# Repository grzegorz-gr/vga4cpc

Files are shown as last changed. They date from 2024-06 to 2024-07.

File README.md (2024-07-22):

# vga4cpc
VGA output for Amstrad CPC based on Raspberry Pi Pico.<br /> <br />

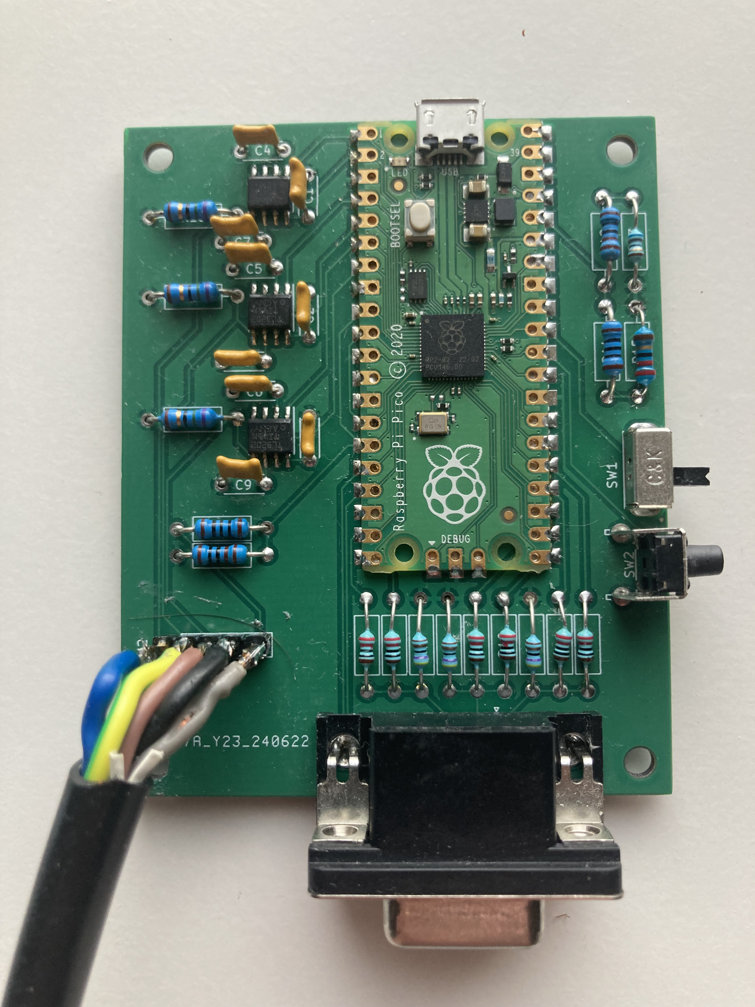
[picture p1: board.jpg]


The goal of this project was to build a scandoubler for Amstrad CPC that is cheap, simple to build and can handle the most popular tricks that Amstrad software does (e.g. smooth scroll) that standard scandoublers usually don't support.
It should work with most LCD monitors. It supports 50.08 FPS to make animations look smoother, but there is also an option to use 60 FPS, if your monitor does not support low frequencies.

Please keep in mind that I am a beginner in electronics, so I could make some serious mistakes. Use it on your own risk.

## Short demo
[https://youtu.be/5xjjsLVpjv0]

## How to build it
Gerber files are in "gerber" directory. I used them with JLCPCB. <br /><br />
Parts:<br />
|Symbol|Value|Quantity|Link|
|---|---|---|---|
|U1|Raspberry Pi Pico|1|[https://www.digikey.com/en/products/detail/raspberry-pi/SC0915/13624793]|
|U2-U4|TLV3202 voltage comparators|3|[https://www.digikey.com/en/products/detail/texas-instruments/TLV3202AIDR/3518740]|
|J1|VGA Socket|1|[https://www.digikey.com/en/products/detail/assmann-wsw-components/A-HDF15A-KG-TAXB/1241905] (Actually it did not fit perfectly, but it was possible to mount it)|
|C1-C9|0.1u ceramic capacitors|9|[https://www.digikey.com/en/products/detail/kyocera-avx/SR215C104JAR/2208907]|
|R1-R3|47 ohm resistors|3|[https://www.digikey.com/en/products/detail/stackpole-electronics-inc/RNMF14FTC47R0/2617352]|
|R4,R14|100 ohm resistors|2|[https://www.digikey.com/en/products/detail/yageo/MFR-25FRF52-100R/14795]|
|R5,R12|1 kOhm resistors|2|[https://www.digikey.com/en/products/detail/yageo/MFR-25FRF52-1K/14891]|
|R6-R11|220 Ohm resistors|6||[https://www.digikey.com/en/products/detail/stackpole-electronics-inc/RNMF14FTC220R/2617314]|
|R13|68 Ohm resistor|1|[https://www.digikey.com/en/products/detail/stackpole-electronics-inc/RNMF14FTC68R0/2617372]|
|R15|22 Ohm resistor|1|[https://www.digikey.com/en/products/detail/yageo/MFR-25FTE52-15R/9139795]|
|R16-R18|75 Ohm resistors|3|[https://www.digikey.com/en/products/detail/yageo/MFR-25FBF52-75R/12771]|
|SW1|50/60 FPS switch|1|[https://www.digikey.com/en/products/detail/c-k/OS102011MA1QS1/1981431]|
|SW2|Reset button|1|[https://www.digikey.com/en/products/detail/te-connectivity-alcoswitch-switches/1-1825027-1/1632544]|
|J2|CPC connection header|1|Just install whatever you need to connect to CPC. I used pin headers and soldered cables to them|
||Din 6 or Din 5 plug (center pin is not used) to connect it to Amstrad unless you plan to solder it directly to PCB|1||

<br /><br />
I wanted to make it easy to solder so almost all parts are TH. Raspberry Pi Pico and comparators are SMD (there was no TH option), but they are quite big and they are simple to solder even without a microscope.
<br /><br />
You need to connect it to Amstrad video port using J2 connector. The pins are: 1 - blue, 2 - green, 3 - red, 4 - GND, 5 - csync. You can connect din-6/din-5 plug there, or solder directly to Amstrad PCB.
<br /><br />
After (or before) building the PCB you just need to upload the software to RPI Pico. Connect it with USB cable to PC/Mac, keeping the small button on Pico board pressed. It should mount as a storage device. Just copy uf2 file there. Pico should unmount and restart then.

## How to use it
Connect 5V power adapter (or just cable to USB port in pc) to RPI Pico. Connect VGA cable to monitor. You can connect the board to Amstrad, but don't turn it on yet. You should see test screen with Amstrad palette on top, some potentially problematic patterns on bottom and 4 squares in corners. Make sure it looks OK. In case of any issues you can try to reset the board with SW2 button. It is also a good moment to try switching the V frequency with SW1 button. If 50.08hz works with your monitor, then use it. In other case, try 60Hz. If squares in corners are not fully visible (the image is shifted), try using Auto-adjust in your monitor.<br />
If everything looks OK, turn on your Amstrad and have fun.<br />

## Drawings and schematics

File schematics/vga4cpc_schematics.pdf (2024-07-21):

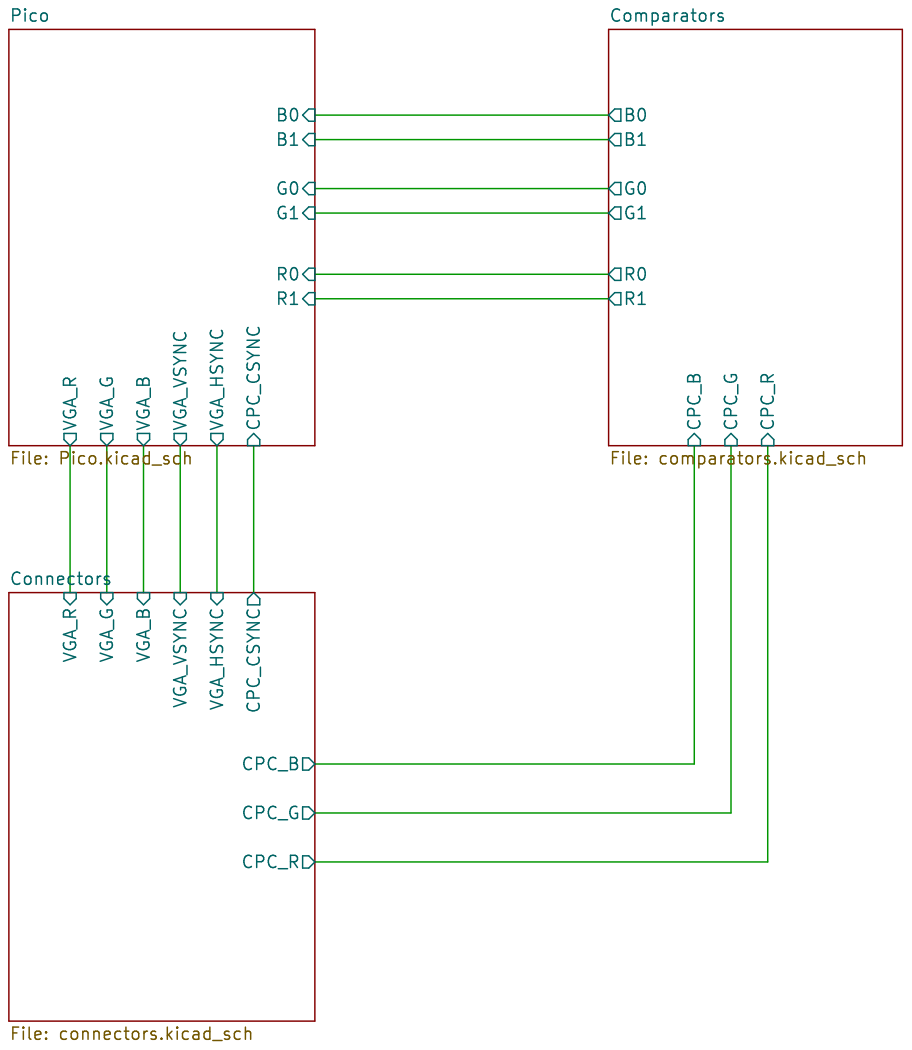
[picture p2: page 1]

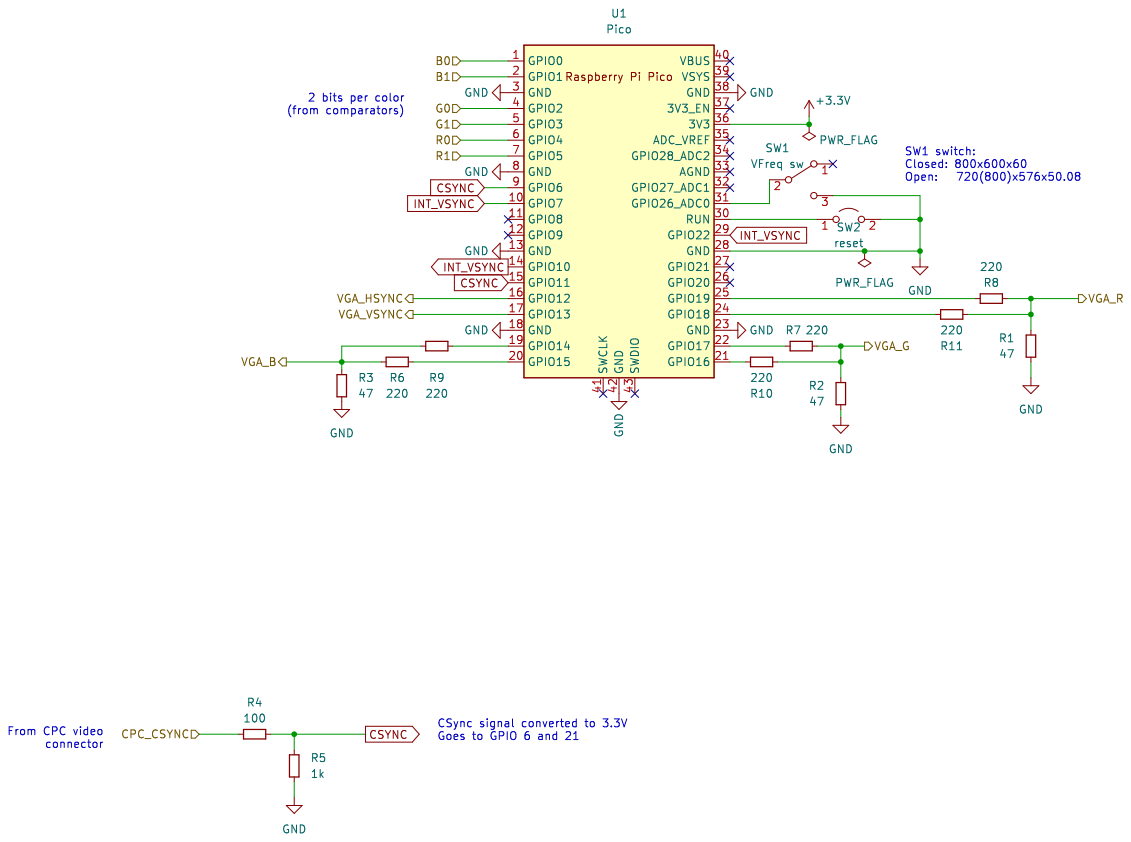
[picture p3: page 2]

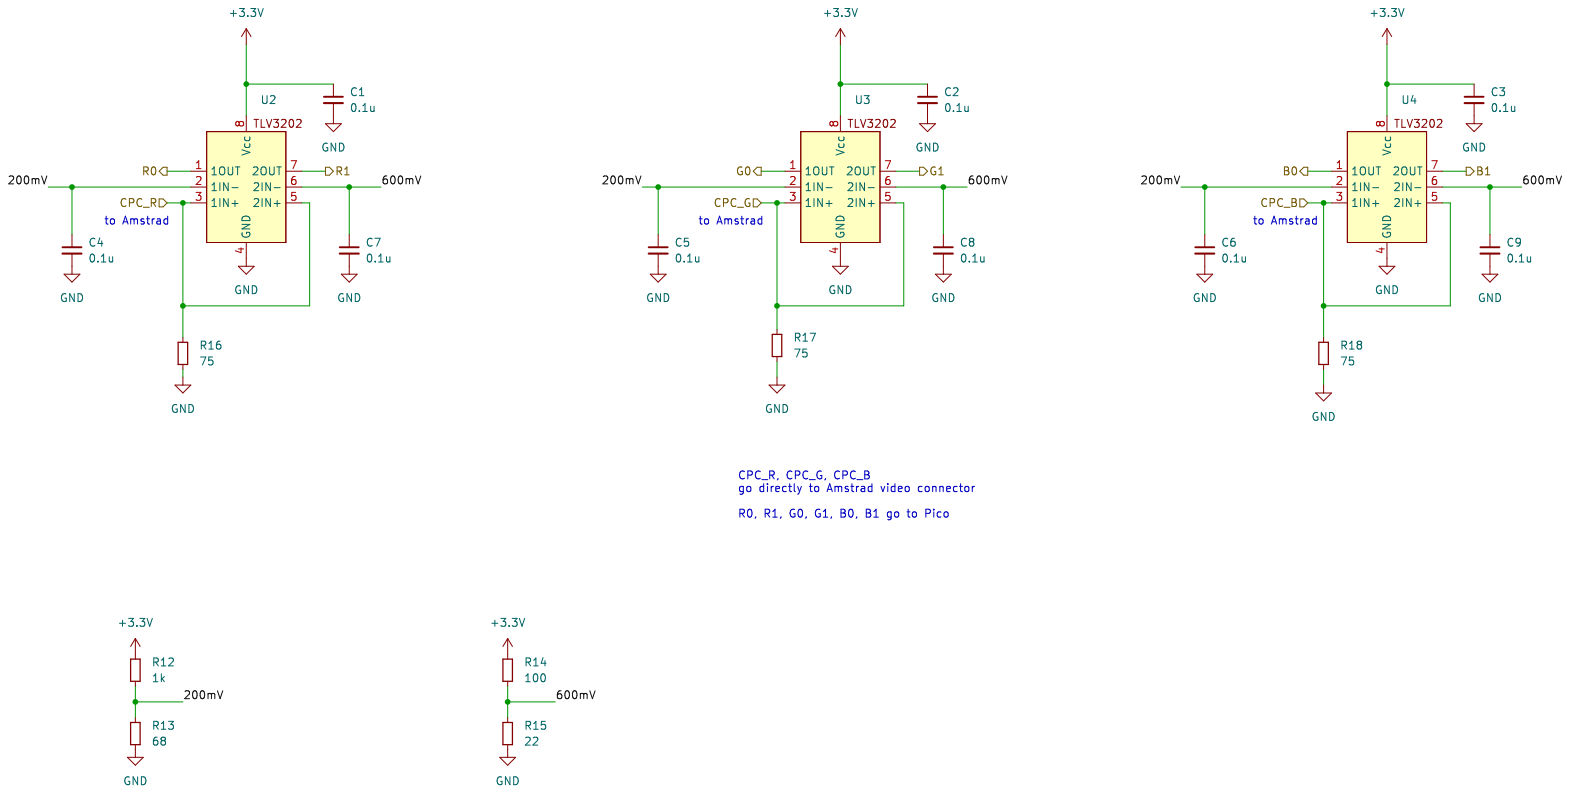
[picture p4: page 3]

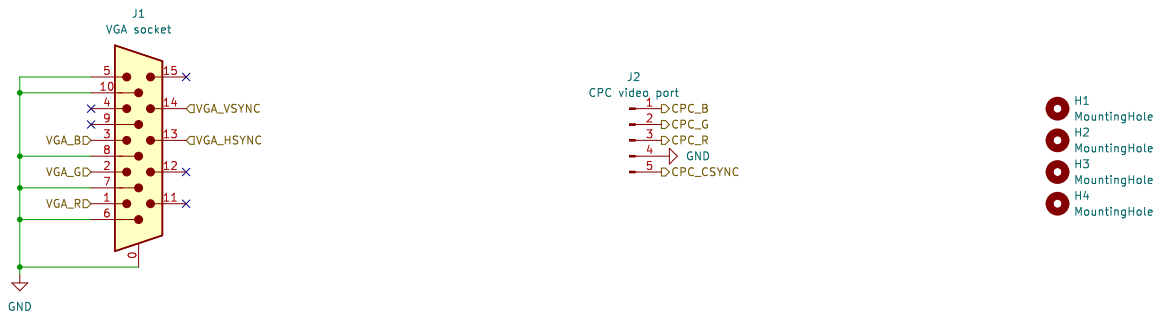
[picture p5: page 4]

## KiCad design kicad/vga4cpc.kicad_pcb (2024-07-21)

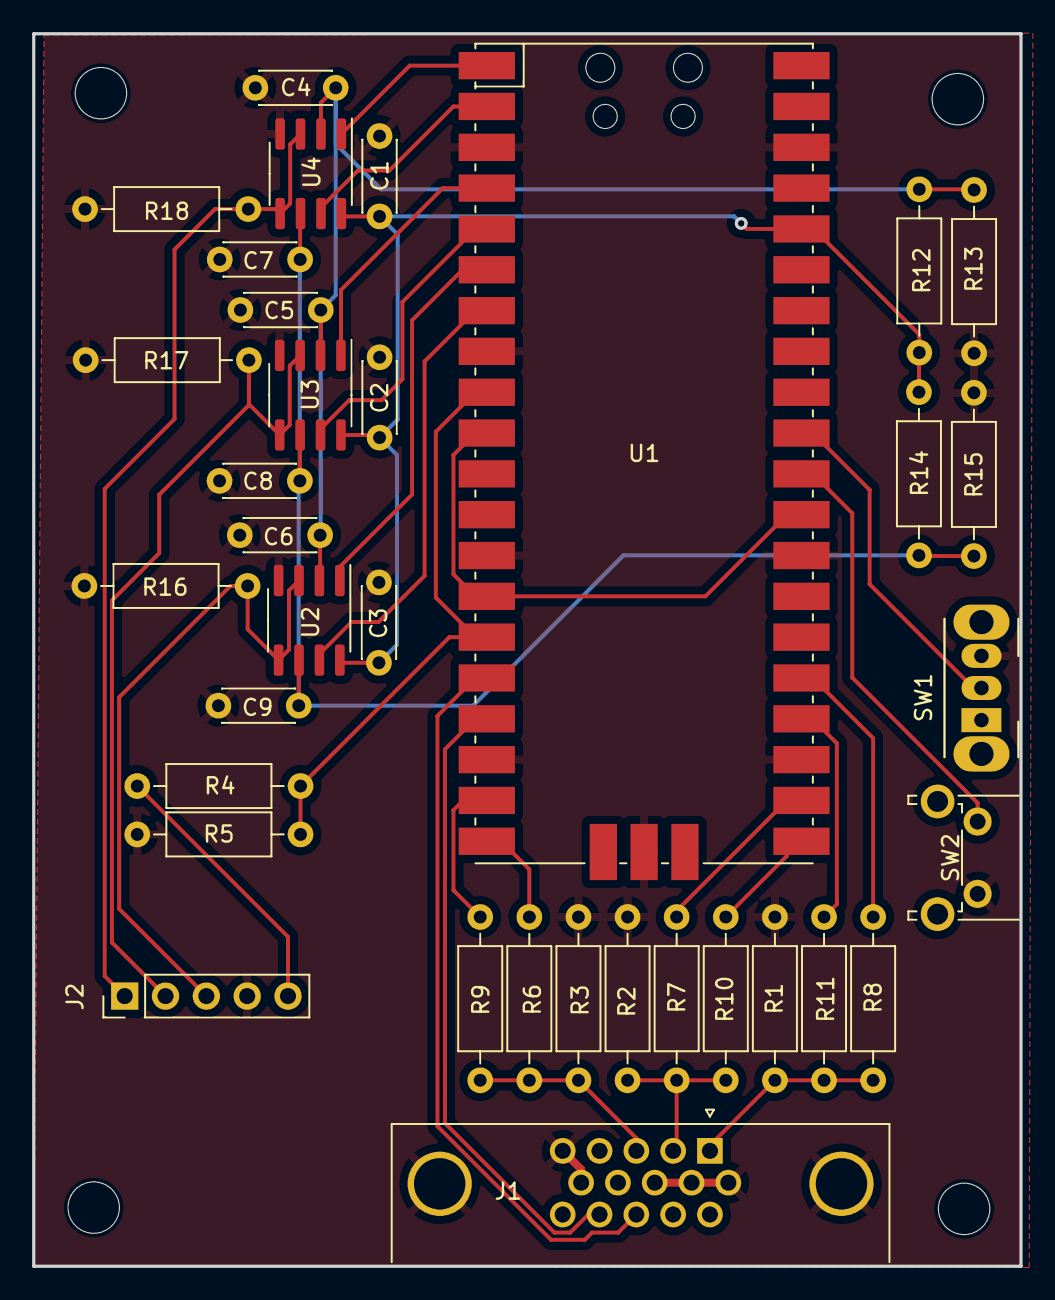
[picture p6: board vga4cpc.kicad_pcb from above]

Board: 2 copper layers, 61.4 x 76.7 mm, 39 parts (0 on the bottom side), 29 nets.

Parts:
C1, C2, C3, C4, C5, C6, C7, C8, C9: 0.1u; C_Disc_D4.3mm_W1.9mm_P5.00mm
H1, H2, H3, H4: MountingHole; MountingHole_3.2mm_M3
J1: VGA socket; DSUB-15-HD_Female_Horizontal_P2.29x1.98mm_EdgePinOffset3.03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
J2: CPC video port; PinHeader_1x05_P2.54mm_Vertical
R1, R2, R3: 47; R_Axial_DIN0207_L6.3mm_D2.5mm_P10.16mm_Horizontal
R4, R14: 100; R_Axial_DIN0207_L6.3mm_D2.5mm_P10.16mm_Horizontal
R5, R12: 1k; R_Axial_DIN0207_L6.3mm_D2.5mm_P10.16mm_Horizontal
R6, R7, R8, R9, R10, R11: 220; R_Axial_DIN0207_L6.3mm_D2.5mm_P10.16mm_Horizontal
R13: 68; R_Axial_DIN0207_L6.3mm_D2.5mm_P10.16mm_Horizontal
R15: 15; R_Axial_DIN0207_L6.3mm_D2.5mm_P10.16mm_Horizontal
R16, R17, R18: 75; R_Axial_DIN0207_L6.3mm_D2.5mm_P10.16mm_Horizontal
SW1: VFreq sw; SW_CuK_OS102011MA1QN1_SPDT_Angled
SW2: reset; SW_Tactile_SPST_Angled_PTS645Vx31-2LFS
U1: Pico; RPi_Pico_SMD_TH
U2, U3, U4: SOIC-8_3.9x4.9mm_P1.27mm

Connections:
200mV: C4.1, C5.1, C6.1, R12.2, R13.1, U2.2 (1IN-), U3.2 (1IN-), U4.2 (1IN-)
430mV: C7.1, C8.1, C9.1, R14.2, R15.1, U2.6 (2IN-), U3.6 (2IN-), U4.6 (2IN-)
+3.3V: C1.1, C2.1, C3.1, R12.1, R14.1, U1.36 (3V3), U2.8 (Vcc), U3.8 (Vcc), U4.8 (Vcc)
/Comparators/B0: U1.1 (GPIO0), U4.1 (1OUT)
/Comparators/B1: U1.2 (GPIO1), U4.7 (2OUT)
/Comparators/CPC_B: J2.1, R18.1, U4.3 (1IN+), U4.5 (2IN+)
/Comparators/CPC_G: J2.2, R17.1, U3.3 (1IN+), U3.5 (2IN+)
/Comparators/CPC_R: J2.3, R16.1, U2.3 (1IN+), U2.5 (2IN+)
/Comparators/G0: U1.4 (GPIO2), U3.1 (1OUT)
/Comparators/G1: U1.5 (GPIO3), U3.7 (2OUT)
/Comparators/R0: U1.6 (GPIO4), U2.1 (1OUT)
/Comparators/R1: U1.7 (GPIO5), U2.7 (2OUT)
/Connectors/CPC_CSYNC: J2.5, R4.1
/Connectors/VGA_B: J1.3, R3.1, R6.2, R9.2
/Connectors/VGA_G: J1.2, R2.1, R7.2, R10.2
/Connectors/VGA_HSYNC: J1.13, U1.16 (GPIO12)
/Connectors/VGA_R: J1.1, R1.1, R8.2, R11.2
/Connectors/VGA_VSYNC: J1.14, U1.17 (GPIO13)
CSYNC: R4.2, R5.1, U1.9 (GPIO6), U1.15 (GPIO11)
GND: C1.2, C2.2, C3.2, C4.2, C5.2, C6.2, C7.2, C8.2, C9.2, J1.0, J1.5, J1.6, J1.7, J1.8, J1.10, J2.4, R1.2, R2.2, R3.2, R5.2, R13.2, R15.2, R16.2, R17.2, R18.2, SW1.3 (C), SW2.2 (B), U1.3 (GND), U1.8 (GND), U1.13 (GND), U1.18 (GND), U1.23 (GND), U1.28 (GND), U1.38 (GND), U1.42 (GND), U2.4 (GND), U3.4 (GND), U4.4 (GND)
INT_VSYNC: U1.10 (GPIO7), U1.14 (GPIO10), U1.29 (GPIO22)
unnamed: SW1.2 (B), U1.31 (GPIO26_ADC0)
unnamed: SW2.1 (A), U1.30 (RUN)
unnamed: R9.1, U1.19 (GPIO14)
unnamed: R6.1, U1.20 (GPIO15)
unnamed: R10.1, U1.21 (GPIO16)
unnamed: R7.1, U1.22 (GPIO17)
unnamed: R11.1, U1.24 (GPIO18)
unnamed: R8.1, U1.25 (GPIO19)

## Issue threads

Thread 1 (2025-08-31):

R4/R5 values inverted on pcb

orzel, 2025-08-31:
If you go on the pcbeditor, the 'values' for R4 is on R5, and the one for R5 is on R4, tha'ts misleading.

The references are ok, and are the values/references on the schematics.

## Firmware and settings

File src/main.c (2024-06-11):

// VGA for Amstrad CPC by gregg

#include <string.h>
#include "pico/stdlib.h"
#include "test_screen.h"
#include "mode_switch.h"
#include "vga_dma.h"
#include "cpc_dma.h"
#include "vga_pio.h"
#include "cpc_pio.h"
#include "constants.h"


// Just a copy of amstrad screen. Each byte corresponds to one pixel (mode 2). Only 6 bits are used - 2 for each rgb color.
// 00 means no color, 01 or 10 is half brightness, and 11 is full brightness.
uint8_t screen[CPC_SCREEN_WIDTH * CPC_SCREEN_HEIGHT];


int main() {
    // It is way more important to accurately time reading from CPC then writing to VGA.
    // Because of that, system clock should be divisible by CPC pixel clock.
    // CPC pixel clock in mode 2 is 16Mhz. When we set system clock to 128Mhz (instead of standard 125Mhz),
    // we can read one pixel in exactly 8 cycles.
    set_sys_clock_khz(128000, true);

    setup_vfreq_and_switch();
    fill_test_screen(screen);
    setup_vga_pio(is_50hz());
    setup_cpc_pio();
    setup_vga_dma(screen, is_50hz());
    start_vga_pio();
    start_vga_dma();
    start_cpc_dma_loop(screen);

    return 0;
}

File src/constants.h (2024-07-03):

#ifndef __CONSTANTS_H__
#define __CONSTANTS_H__

#include "hardware/pio.h"

// Pico GPIO pins assignment. They may change once I move from breadboard prototype to a real pcb.
#define FIRST_RGB_IN_PIN 0   // First of 8 inputs: blue, blue, green, green, red, red, csync, vsync
#define CSYNC_IN_PIN_PIO 6   // csync pin from Amstrad to PIO
#define FIRST_RGB_OUT_PIN 14  // First of 6 outputs: blue, blue, green, green, red, red
#define HSYNC_OUT_PIN 12     // VGA horizontal sync signal
#define VSYNC_OUT_PIN 13     // VGA vertical sync signal
#define VSYNC_GENERATOR_OUT_PIN 10  // Input vsync signal separated from csync. Goes to pin 7 and 22.
#define CSYNC_IN_PIN_HOST 11 // csync pin from Amstrad to host
#define VSYNC_IN_PIN_HOST 22 // vsync pin from VSYNC generating pio to host
#define VFREQ_SWITCH_PIN 26  // Switch between 576p50 (connected to GND) and 800x600p60 (not connected)

// Active width and height of CPC screen, and also the size of the copy that we keep in ram.
#define CPC_SCREEN_WIDTH 800
#define CPC_SCREEN_HEIGHT 296

// PIO for generating output (3 SMs - vsync, hsync and rgb)
#define VGA_PIO pio0
// PIO for reading input (2 SMs - one read rgb and one extracts vsync from csync)
#define CPC_PIO pio1

// State machines
#define VSYNC_GENERATOR_SM 0    // Reads CSync and generates VSync out of it. Output is used by both host and RGB_IN_SM
#define RGB_IN_SM 1             // Reads pixels from input and sends to host (rgbin.pio)
#define HSYNC_OUT_SM 0          // Generates output HSync signal (hsync_50.pio | hsync_60.pio)
#define VSYNC_OUT_SM 1          // Generates output VSync signal (hsync_50.pio | hsync_60.pio)
#define RGB_OUT_SM 2            // Generates output RGB signal (rgb_50.pio | rgb_60.pio)

// DMA channels
#define RGB_IN_CHANNEL 0            // for pixels from RGB_IN_SM to host
#define RGB_OUT_CONFIG_CHANNEL_A 1  // configures RGB_OUT_CHANNEL
#define RGB_OUT_CONFIG_CHANNEL_B 2  // configures RGB_OUT_CHANNEL
#define RGB_OUT_CONFIG_CHANNEL_C 3  // configures RGB_OUT_CHANNEL
#define RGB_OUT_CHANNEL 4           // for pixels from host to RGB_OUT_SM

#endif

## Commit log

2024-06-12 Schematics draft pdf
2024-07-03 Bugfix in csync analysis (Fixes Edge Grinder) and a couple more
    [constants.h]
2024-07-15 A couple bugs fixed
    [cpc_dma.c]
2024-07-21 Schematics, gerbers, kicad
    [Pico.kicad_sch, comparators.kicad_sch, connectors.kicad_sch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]
2024-07-22 board photo
